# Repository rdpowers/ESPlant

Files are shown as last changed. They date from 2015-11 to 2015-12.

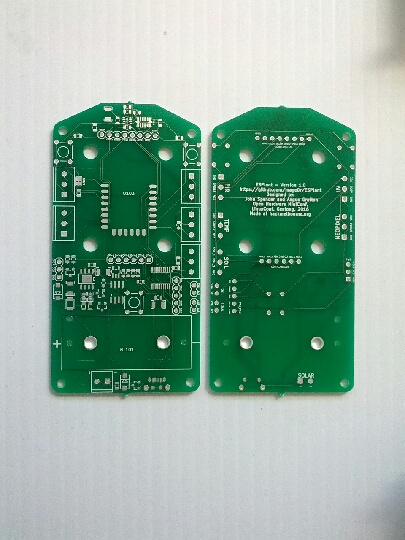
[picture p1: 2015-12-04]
Photos/download_20151204_143113.jpg

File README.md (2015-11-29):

ESPlant - Environment Sensor Plant
=============

Welcome to the linux.conf.au Open Hardware Project.  You can see information about this and other MiniConfs at http://www.openhardwareconf.org/wiki/Main_Page

The ESPlant kit is designed to provide an open source platform to transmit environmental data to a central source using the power of wifi.

Circuit at Gerblook.org: http://gerblook.org/pcb/yRvGzKC4G7xZh2MVUVMHdD#front

Worst mock up ever!
Mockup mockup

CREDITS
------------

This project was designed by the 2016 linux.conf.au Open Hardware Team!
 - John Spencer
 - Angus Gratton
 - Andy Gelme
 - Jon Oxer

You can see our githubs at:
 - https://github.com/mage0r
 - https://github.com/projectgus
 - https://github.com/geekscape
 - https://github.com/jonoxer

Made at hackmelbourne.org!

SPECIAL THANKS
------------

To the HackMelbourne (CCHS, http://hackmelbourne.org) community of Melbourne, Australia.

To all other open-source developers whose countless hours supported every other aspect of this design.

DISTRIBUTION
------------
The specific terms of distribution of this project are governed by the
license referenced below. Please contact the copyright owner if you wish to modify the board for distribution. Please utilize this design for personal or research projects. Please acknowledge all contributors.

LICENSE
-------
Licensed under the TAPR Open Hardware License (www.tapr.org/OHL).
The "license" sub-folder also contains a copy of this license in plain text format.

Copyright John Spencer, Angus Gratton, Andy Gelme, Jon Oxer 2015

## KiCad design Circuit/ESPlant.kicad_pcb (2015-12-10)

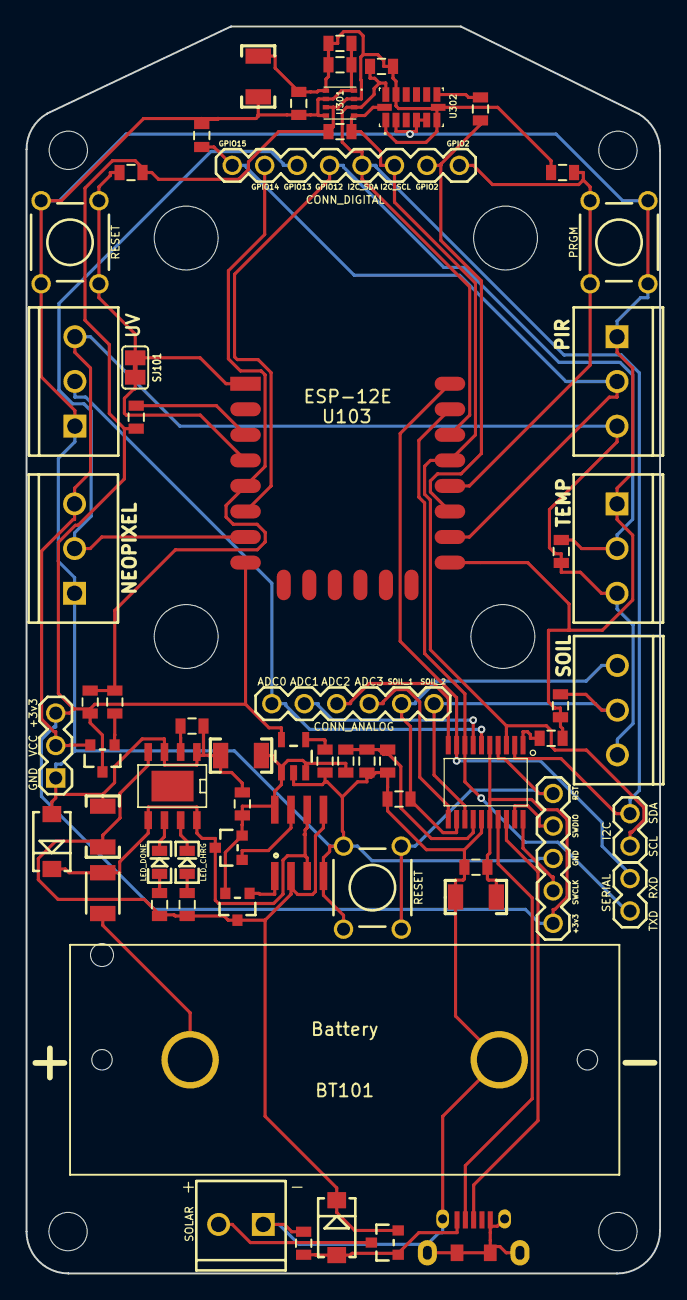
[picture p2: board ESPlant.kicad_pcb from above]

Board: 2 copper layers, 49.6 x 97.6 mm, 72 parts (0 on the bottom side), 45 nets.

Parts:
BT101: Battery; CR123_Holder
C101, C104, C202: 100nF; 0805
C102, C107: 100nF 6.3V; 0805
C103, C201: 10uF 16V; 1210_CAP
C106, C203: 220uF 16V; 1210_CAP
C301, C302: 1uF 6.3V; 0805
D101, D201: SS14; DIODE_SMA
F101: 1A PTC; 1210
LED201: LED_DONE; LED-0805
LED202: LED_CHRG; LED-0805
P1: SOIL; SCREWTERMINAL-3.5MM-3
P101: CONN_DIGITAL; 1X08
P102: CONN_ANALOG; 1X06
P103: SERIAL; 1X02
P104: I2C; 1X02
P105: SOLAR; SCREWTERMINAL-3.5MM-2
P106: USB_5PIN_SHELL; USB-MICRO-5pin_PTHMOUNT
P109: PWR; 1X03
P110: STM_PGM; 1X05
P111: UV; SCREWTERMINAL-3.5MM-3
P112: TEMP; SCREWTERMINAL-3.5MM-3
P113: NEOPIXEL; SCREWTERMINAL-3.5MM-3
P114: PIR; SCREWTERMINAL-3.5MM-3
Q101, Q201, Q202, Q203: FDN340P; SOT23_FET
R101: 10K DNP; 0805
R102, R103: 100K; 0805
R104, R105, R109, R111, R112, R113: 10K; 0805
R106, R201: 1K; 0805
R107: 56K 1%; 0805
R108: 47K 1%; 0805
R110: 4.7K DNP; 0805
R202, R203: 330R; 0805
R204: 8.2K; 0805
R301, R302: 4.7K; 0805
REF01, REF02, REF03, REF04: MOUNT; MountingHole_5mm
REF05, REF06, REF07, REF08: MOUNT; MountingHole_3mm
REG101: SPX3819M5; SOT23-5
SJ101: SJ; SJ_SHORTED
SW101, SW103: RESET; SW_PUSHBUTTON_PTH
SW102: PRGM; SW_PUSHBUTTON_PTH
U101: STM32F042F; TSSOP20_4mm
U103: ESP-12E
U201: CN3063; CN3063_SOIC8_EP
U202: MCP6002; SO08_4mm
U301: BME280
U302: ADXL345

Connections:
+3V3: C102.1, C103.1, C106.1, C107.1, C301.1, C302.1, P109.1, P110.1, Q101.D, R104.1, R111.2, R112.2, R113.1, R301.1, R302.1, REG101.5, U101.5, U101.16, U103.8, U301.2, U301.6, U301.8, U302.1, U302.6, U302.7, U302.12
/ADC0: P102.1, P111.2, U101.6
/ADC1: P102.2, U101.7
/ADC2: P102.3, U101.10
/ADC3: P102.4, U101.11
/BAT+: BT101.1, F101.1
/ESP_EN: R113.2, U103.3
/ESP_~RESET: R111.1, SJ101.1, SW101.2, U103.1
/GPIO0: P101.1, R112.1, SW102.2, U103.18
/GPIO2: P101.2, R105.1, U103.17
/GPIO12: P101.5, P112.2, R110.2, U103.6
/GPIO13: P101.6, P113.2, U103.7
/GPIO14: P101.7, R104.2, R106.2, U103.5
/GPIO15: P101.8, P114.2, R109.1, U103.16
/GPIO16: SJ101.2, U103.4
/I2C Sensors/ADXL_INT: R105.2, U302.8
/I2C Sensors/I2C_SCL: P101.3, P104.1, R302.2, U101.3, U103.19, U301.4, U302.14
/I2C Sensors/I2C_SDA: P101.4, P104.2, R301.2, U101.2, U103.20, U301.3, U302.13
/Power/GBAT: Q203.G, U202.7
/Power/GIN: Q202.G, U202.1
/Power/SOLAR_IN: P105.1, Q201.D
/Power/USB_IN: D201.A, P106.1, Q201.G, R201.1
/Power/VBAT: D101.K, F101.2, Q203.D, U201.5, U201.8, U202.3, U202.6
/Power/VIN: C201.1, D201.K, Q201.S, Q202.D, R202.1, R203.1, U201.4, U202.2, U202.5
/Power/VOUT: C202.1, C203.2, Q202.S, Q203.S, R107.1, REG101.1, REG101.3, U202.8
/Power/~CHRG: LED202.K, U201.7
/Power/~DONE: LED201.K, U201.6
/SOIL_1: P1.3, P102.5, R102.1, U101.12
/SOIL_2: P1.2, P102.6, R103.1, U101.13
/STM_BOOT: R101.1, U101.1
/STM_RXD: P103.1, U101.9, U103.22
/STM_SWCLK: P110.2, U101.20
/STM_SWDIO: P110.4, U101.19
/STM_TXD: P103.2, U101.8, U103.21
/STM_~RESET: P110.5, SW103.2, U101.4
/USB_D+: P106.3, U101.18
/USB_D-: P106.2, U101.17
/VCC_SENS: P1.1, P109.2, P111.1, P112.1, P113.1, P114.1, Q101.S, R110.1
GND: BT101.2, C101.2, C102.2, C103.2, C104.2, C106.2, C107.2, C201.2, C202.2, C203.1, C301.2, C302.2, D101.A, P105.2, P106.5, P106.SHLD, P109.3, P110.3, P111.3, P112.3, P113.3, P114.3, R101.2, R102.2, R103.2, R108.2, R109.2, R201.2, R204.2, REG101.2, SW101.1, SW102.1, SW103.1, U101.15, U103.15, U201.1, U201.3, U202.4, U301.1, U301.5, U301.7, U302.2, U302.4, U302.5
unnamed: C101.1, REG101.4
unnamed: C104.1, R107.2, R108.1, U101.14
unnamed: LED201.A, R202.2
unnamed: LED202.A, R203.2
unnamed: Q101.G, R106.1
unnamed: R204.1, U201.2

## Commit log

2015-11-28 10x5 PCB design.
    [ESPlant.dsn]
2015-11-29 5 Vias, no text.
    [ESPlant.dsn, ESPlant.kicad_pcb, _saved_ESPlant.sch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]
2015-11-29 Traces in.
    [ESPlant.kicad_pcb, ESPlant.sch, Power.sch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]
2015-11-29 Added text.
    [ESPlant.kicad_pcb]
2015-12-04 Adding photo of actual boards.
2015-12-04 Updated the silkscreen text
    [ESPlant.kicad_pcb]
2015-12-10 Updates to silkscreen.
    [ESPlant.kicad_pcb]
